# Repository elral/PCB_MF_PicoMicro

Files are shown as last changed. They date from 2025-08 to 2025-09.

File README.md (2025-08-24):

# ✈️ PicoMicro - ProMicro-Compatible Board from Mobiflight

This board is designed as a **drop-in replacement** for the classic Arduino Pro Micro (ATmega32U4), but powered by the **modern Raspberry Pi RP2350A microcontroller**.  
It keeps the same **form factor and pinout** while offering massive improvements in performance, memory, and connectivity — making it the **ideal choice for Mobiflight cockpits**.

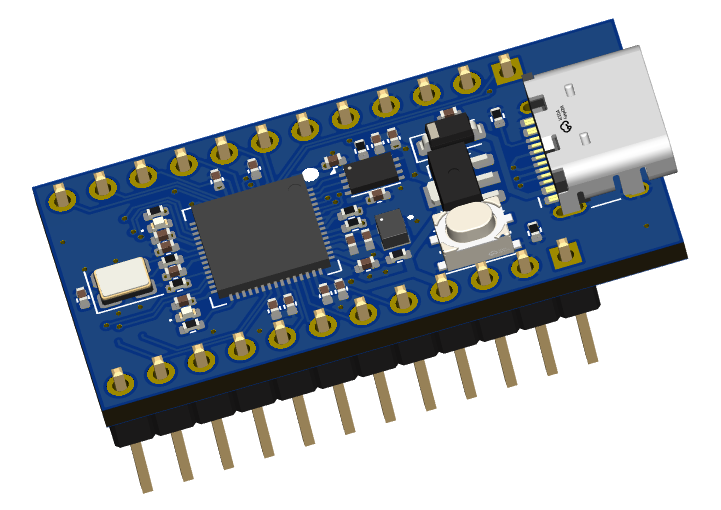
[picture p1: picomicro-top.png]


---

## 🚀 Why PicoMicro for Mobiflight?

### ⚡ Drop-In Upgrade
- Identical footprint & pinout to the Arduino Pro Micro  
- Works with existing wiring and PCB layouts → **no hardware redesign required**  

### 📈 Higher Performance for Complex Cockpits
- **Dual-core ARM Cortex-M33 @ up to 150 MHz** (with FPU & DSP)  
- Handles many encoders, switches, LEDs, and displays simultaneously  
- **512 KB SRAM + up to 16 MB Flash** → no memory limits for complex setups  

### 🔌 Richer Connectivity
- **Native USB 2.0 FS/HS**  

### ⚡ True 5V Compatibility
- **5V-tolerant I/O pins** → safe with legacy 5V sensors, LEDs, and modules  
- Fully compatible with most cockpit electronics  

### 🔋 Efficiency & Reliability
- ARM-based low-power modes for large setups  
- Stable & future-proof, backed by Raspberry Pi Foundation support

---

## ⚠️ Known Limitations vs. Arduino Pro Micro

While this board is highly compatible, there are a few important differences:

1. **Analog Inputs**  
   - Only **A0 to A3** are available (4 total)  
   - Other analog pins present on the Pro Micro are not supported  

2. **5V Output (Pin 21)**  
   - On the Arduino Pro Micro, Pin 21 outputs **5V**  
   - On this board, Pin 21 outputs **3.3V**  

3. **MAX7219 & 5V Requirement**  
   - The MAX7219 driver must still be powered with **5V**  
   - Therefore, an **external 5V source** is required, or you can use **Pin 24 (Vin)**, which provides 5V directly from the USB connector  

4. **Level Shifting for MAX7219**  
   - The MAX7219 requires **5V logic levels**  
   - Use a **level shifter** between the PicoMicro board (3.3V signals) and the MAX7219 inputs  

5. **Bootloader Button**  
   - The board includes a **dedicated BOOT button** to enter USB mass storage boot mode (for firmware flashing).  

---

## 📊 PicoMicro vs. Arduino Pro Micro (ATmega32U4)

| Feature  | PicoMicro ProMicro | Arduino Pro Micro (ATmega32U4) |
|---|---|---|
| MCU | Dual-core ARM Cortex-M33 @ up to 150 MHz, FPU, DSP | 8-bit AVR @ 16 MHz |
| Flash | Up to 16 MB QSPI (typ. 2–8 MB onboard) | 32 KB |
| RAM | 512 KB | 2.5 KB |
| USB | Native USB 2.0 FS/HS, multiple device classes | Native USB 2.0 FS (limited) |
| I/O | **3.3 V logic, 5 V-tolerant pins** | 5 V I/O (native) |
| Analog | 4 (A0–A3 only) | 12 (depending on variant) |
| Extra HW | 2× PIO, Crypto engine, more UART/SPI/I²C | – |
| Power | Low-power modes, efficient ARM design | Limited power saving |

---

## 🔧 Example Wiring (MAX7219 with External 5V)

When using a MAX7219 with this PicoMicro board, note the following:

- The MAX7219 **requires 5V power** for reliable operation.
- The PicoMicro board only provides **3.3V logic**, so a **level shifter** is required on the SPI signals.
- Use the `Vin` pin (Pin 24, USB 5V) as the 5V source if no external supply is available.
- Do **not** use Pin 21 (`5V`), as it only provides 3.3V on this board.

#### Wiring Notes

- **Vin (5V USB)** → **VCC (5V MAX7219)**
- **GND** → **GND**
- **MOSI (3.3V)** → (via level shifter) → **DIN (5V)**
- **SCK (3.3V)** → (via level shifter) → **CLK (5V)**
- **CS (3.3V)** → (via level shifter) → **LOAD/CS (5V)**

Make sure to add a **3.3V → 5V level shifter** on the SPI signals to the MAX7219.

#### Block Diagram

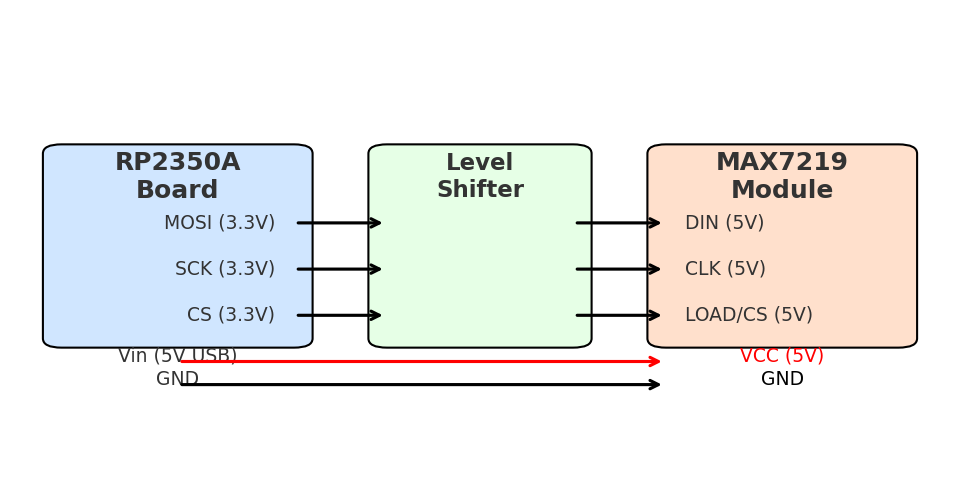
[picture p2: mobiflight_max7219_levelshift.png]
MAX7219 wiring


---

## 🖥 Advantages for Mobiflight Community Devices

Many Mobiflight **Custom Devices** (Community Devices) are more complex and require more memory and processing power than the classic Arduino Pro Micro can provide.  
This board with the **RP2350A** offers clear advantages:

- **More Flash** → room for larger device code and libraries.  
- **More RAM** → essential for OLED displays and complex buffers.  
- **Higher performance** → smoother updates and faster response.  
- **Dual-Core CPU** → allows splitting tasks (e.g., handling displays and inputs in parallel).  
- **PIO offload** → precise timing for LEDs, drivers, or custom protocols  

This makes the PicoMicro board especially well-suited for **community-driven Mobiflight devices**, including setups with **OLED displays** and other resource-demanding modules.

---

## ✈️ Why It Matters for Mobiflight
- **Supports more devices per board** → fewer boards, fewer USB connections
- **Fast response times** → smoother input/output handling with no lag
- **Drop-in compatibility** → works in place of the Pro Micro in your cockpit modules  
- **Future-ready** → while the ATmega32U4 reaches its limits, the PicoMicro provides plenty of headroom for upcoming Mobiflight features  

---

## 📌 Summary
The **PicoMicro** is a **next-generation upgrade** built for Mobiflight cockpit builders:  
✅ More performance & memory  
✅ 5V-tolerant IO  
✅ 100% ProMicro form factor  
✅ Ideal for complex community devices, including OLEDs

> **Upgrade your cockpit today — with transparent compatibility notes for a smooth migration.**

## Additional information

### Bottom View
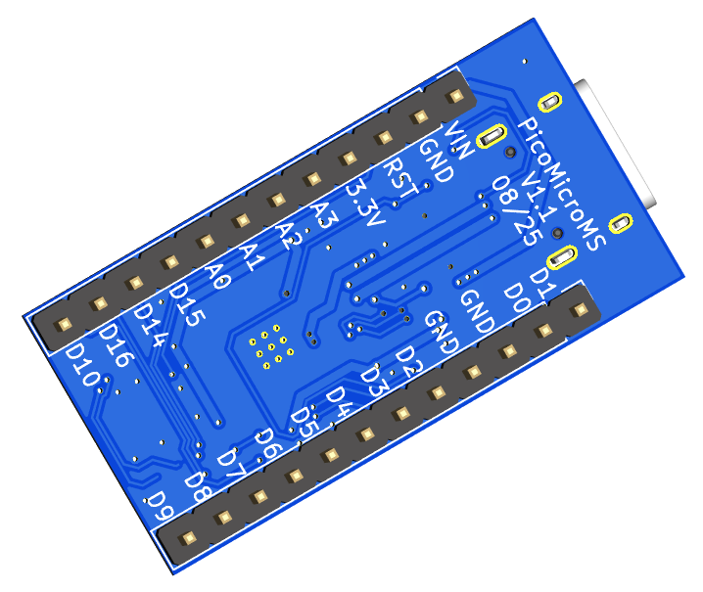
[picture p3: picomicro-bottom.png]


### Schematic
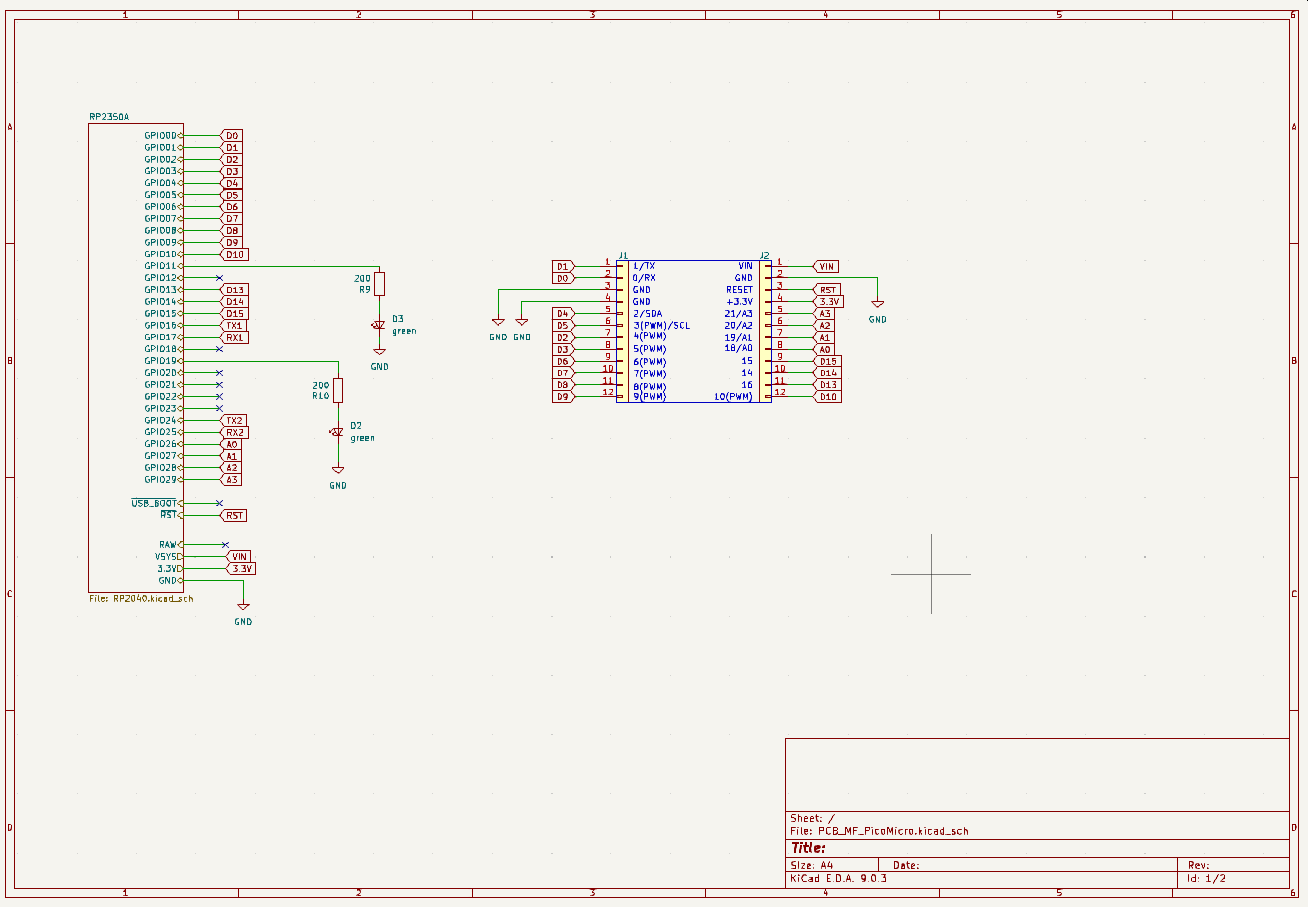
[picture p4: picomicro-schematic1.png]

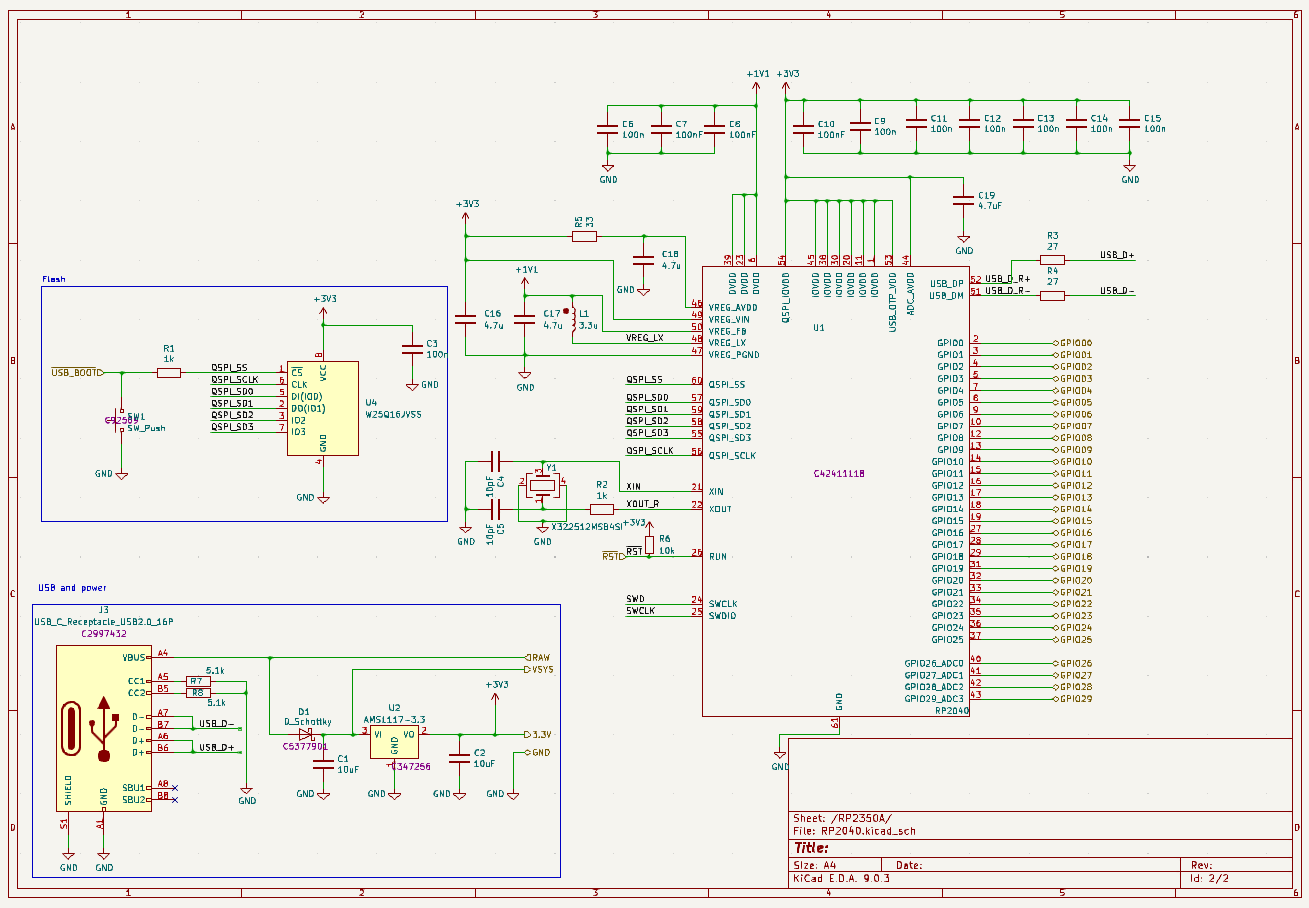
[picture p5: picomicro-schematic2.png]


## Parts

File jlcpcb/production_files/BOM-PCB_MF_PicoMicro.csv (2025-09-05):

Comment | Designator | Footprint | LCSC | Quantity
1k | R1,R2 | R_0402_1005Metric | C11702 | 2
100nF | C10,C11,C12,C13,C14,C15,C3,C6,C7,C8,C9 | C_0402_1005Metric | C1525 | 11
10uF | C1,C2 | C_0402_1005Metric | C15525 | 2
4.7u | C16,C17,C18,C19 | C_0402_1005Metric_small_pads | C23733 | 4
200 | R10,R9 | R_0402_1005Metric | C25087 | 2
27 | R3,R4 | R_0402_1005Metric | C25100 | 2
33 | R5 | R_0402_1005Metric | C25105 | 1
50 | R11,R12 | R_0402_1005Metric | C25120 | 2
10k | R6 | R_0402_1005Metric | C25744 | 1
5.1k | R7,R8 | R_0402_1005Metric | C25905 | 2
W25Q16JVSS | U4 | Winbond_USON-8-1EP_3x2mm_P0.5mm_EP0.2x1.6mm | C2843335 | 1
Conn_01x02_Pin | J7,J8 | JST_ZH_B2B-ZR_1x02_P1.50mm_Vertical | C2845550 | 2
USB_C_Receptacle_USB2.0_16P | J3 | USB_C_Receptacle_HCTL_HC-TYPE-C-16P-01A | C2997432 | 1
10pF | C4,C5 | C_0402_1005Metric | C32949 | 2
AMS1117-3.3 | U2 | SOT-89-3 | C347256 | 1
green | D2,D3 | LED_0402_1005Metric | C401111 | 2
RP2350A | U1 | RP2350A_QFN-60_EP_7.75x7.75_Pitch0.4mm | C42411118 | 1
3.3u | L1 | L_pol_2016 | C42411119 | 1
D_Schottky | D1 | D_SOD-123 | C5377901 | 1
X322512MSB4SI | Y1 | Crystal_SMD_3225-4Pin_3.2x2.5mm | C9002 | 1
SW_Push | SW1 | SW_Push_1P1T_NO_Vertical_Wuerth_434133025816 | C92589 | 1
Conn_01x12 | J2 | PinHeader_1x12_P2.54mm_Vertical |  | 1
Conn_01x12 | J1 | PinHeader_1x12_P2.54mm_Vertical |  | 1

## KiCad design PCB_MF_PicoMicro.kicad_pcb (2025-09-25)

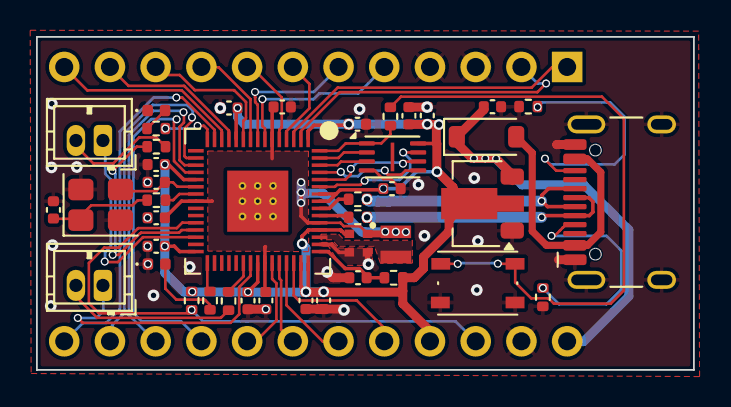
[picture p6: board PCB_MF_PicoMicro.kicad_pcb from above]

Board: 2 copper layers, 36.5 x 18.5 mm, 44 parts (0 on the bottom side), 52 nets.

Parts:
C1, C2: 10uF; C_0402_1005Metric
C3: 100n; C_0402_1005Metric
C4, C5: 10pF; C_0402_1005Metric
C6, C7, C8, C9, C10, C11, C12, C13, C14, C15: 100nF; C_0402_1005Metric
C16, C17: 4.7u; C_0402_1005Metric_small_pads
C18: 4.7u; C_0402_1005Metric
C19: 4.7uF; C_0402_1005Metric
D1: D_Schottky; D_SOD-123
D2, D3: green; LED_0402_1005Metric
J1: PicoMicro
J3: USB_C_Receptacle_USB2.0_16P; USB_C_Receptacle_HCTL_HC-TYPE-C-16P-01A
J7, J8: Conn_01x02_Pin; JST_ZH_B2B-ZR_1x02_P1.50mm_Vertical
L1: 3.3u; L_pol_2016
R1, R2: 1k; R_0402_1005Metric
R3, R4: 27; R_0402_1005Metric
R5: 33; R_0402_1005Metric
R6: 10k; R_0402_1005Metric
R7, R8: 5.1k; R_0402_1005Metric
R9, R10: 200; R_0402_1005Metric
R11, R12: 50; R_0402_1005Metric
SW1: SW_Push; SW_Push_1P1T_NO_Vertical_Wuerth_434133025816
U1: RP2350A; RP2350A_QFN-60_EP_7.75x7.75_Pitch0.4mm
U2: AMS1117-3.3; SOT-89-3
U4: W25Q16JVSS; Winbond_USON-8-1EP_3x2mm_P0.5mm_EP0.2x1.6mm
Y1: X322512MSB4SI; Crystal_SMD_3225-4Pin_3.2x2.5mm

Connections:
3.3V: C2.1, C3.1, C9.1, C10.1, C11.1, C12.1, C13.1, C14.1, C15.1, C16.1, C19.1, J1.21 (+3.3V), R5.1, R6.1, U1.1 (IOVDD), U1.11 (IOVDD), U1.20 (IOVDD), U1.30 (IOVDD), U1.38 (IOVDD), U1.44 (ADC_AVDD), U1.45 (IOVDD), U1.49 (VREG_VIN), U1.53 (USB_OTP_VDD), U1.54 (QSPI_IOVDD), U2.2 (VO), U4.8 (VCC)
+1V1: C6.1, C7.1, C8.1, C17.1, L1.1, U1.6 (DVDD), U1.23 (DVDD), U1.39 (DVDD), U1.50 (VREG_FB)
/RP2350A/GPIO11: R9.2, U1.15 (GPIO11)
/RP2350A/GPIO19: R10.2, U1.31 (GPIO19)
/RP2350A/QSPI_SCLK: U1.56 (QSPI_SCLK), U4.6 (CLK)
/RP2350A/QSPI_SD0: U1.57 (QSPI_SD0), U4.5 (DI(IO0))
/RP2350A/QSPI_SD1: U1.59 (QSPI_SD1), U4.2 (DO(IO1))
/RP2350A/QSPI_SD2: U1.58 (QSPI_SD2), U4.3 (IO2)
/RP2350A/QSPI_SD3: U1.55 (QSPI_SD3), U4.7 (IO3)
/RP2350A/QSPI_SS: R1.1, U1.60 (QSPI_SS), U4.1 (~CS)
/RP2350A/RAW: D1.2 (A), J3.A4 (VBUS), J3.A9 (VBUS), J3.B4 (VBUS), J3.B9 (VBUS)
/RP2350A/USB_D+: J3.A6 (D+), J3.B6 (D+), R3.1
/RP2350A/USB_D-: J3.A7 (D-), J3.B7 (D-), R4.1
/RP2350A/USB_D_R+: R3.2, U1.52 (USB_DP)
/RP2350A/USB_D_R-: R4.2, U1.51 (USB_DM)
/RP2350A/VREG_LX: L1.2, U1.48 (VREG_LX)
/RP2350A/XIN: C4.1, U1.21 (XIN), Y1.3
/RP2350A/XOUT_R: R2.1, U1.22 (XOUT)
/RP2350A/~USB_BOOT: R1.2, SW1.2
A0: J1.17 (18(A0)), U1.40 (GPIO26_ADC0)
A1: J1.18 (19(A1)), U1.41 (GPIO27_ADC1)
A2: J1.19 (20(A2)), U1.42 (GPIO28_ADC2)
A3: J1.20 (21(A3)), U1.43 (GPIO29_ADC3)
D0: J1.2 (0(PWM)/RX), U1.2 (GPIO0)
D1: J1.1 (1(PWM)/TX), U1.3 (GPIO1)
D2: J1.7 (4(PWM)), U1.4 (GPIO2)
D3: J1.8 (5(PWM)), U1.5 (GPIO3)
D4: J1.5 (2(PWM)/SDA), U1.7 (GPIO4)
D5: J1.6 (3(PWM)/SCL), U1.8 (GPIO5)
D6: J1.9 (6(PWM)), U1.9 (GPIO6)
D7: J1.10 (7(PWM)), U1.10 (GPIO7)
D8: J1.11 (8(PWM)), U1.12 (GPIO8)
D9: J1.12 (9(PWM)), U1.13 (GPIO9)
D10: J1.13 (10(PWM)), U1.14 (GPIO10)
D13: J1.14 (16), U1.17 (GPIO13)
D14: J1.15 (14), U1.18 (GPIO14)
D15: J1.16 (15), U1.19 (GPIO15)
GND: C1.2, C2.2, C3.2, C4.2, C5.2, C6.2, C7.2, C8.2, C9.2, C10.2, C11.2, C12.2, C13.2, C14.2, C15.2, C16.2, C17.2, C18.2, C19.2, D2.1 (K), D3.1 (K), J1.3 (GND), J1.4 (GND), J1.23 (GND), J3.A1 (GND), J3.A12 (GND), J3.B1 (GND), J3.B12 (GND), J3.S1 (SHIELD), R7.1, R8.1, SW1.1, U1.47 (VREG_PGND), U1.61 (GND), U2.1 (GND), U4.4 (GND), Y1.2, Y1.4
unnamed: C5.1, R2.2, Y1.1
unnamed: D2.2 (A), R10.1
unnamed: D3.2 (A), R9.1
unnamed: J3.A5 (CC1), R7.2
unnamed: J3.B5 (CC2), R8.2
unnamed: J7.2, R11.1
unnamed: J8.2, R12.1
unnamed: C18.1, R5.2, U1.46 (VREG_AVDD)
RST: J1.22 (RESET), R6.2, U1.26 (RUN)
RX1: J7.1, U1.28 (GPIO17)
RX2: J8.1, U1.37 (GPIO25)
TX1: R11.2, U1.27 (GPIO16)
TX2: R12.2, U1.36 (GPIO24)
VIN: C1.1, D1.1 (K), J1.24 (VIN), U2.3 (VI)

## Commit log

2025-08-09 first upload
    [PCB_MF_PicoMicro.kicad_pcb, PCB_MF_PicoMicro.kicad_sch, RP2040.kicad_sch]
2025-08-09 first changes for RP2350A
    [PCB_MF_PicoMicro.kicad_pcb, PCB_MF_PicoMicro.kicad_sch, RP2040.kicad_sch]
2025-08-10 power supply lines routed
    [PCB_MF_PicoMicro.kicad_pcb, RP2040.kicad_sch]
2025-08-11 fixed all warnings/errors
    [PCB_MF_PicoMicro.kicad_pcb, RP2040.kicad_sch]
2025-08-11 add parts for 1.1V regulator
    [PCB_MF_PicoMicro.kicad_pcb, RP2040.kicad_sch]
2025-08-12 add LED, make board smaller
    [PCB_MF_PicoMicro.kicad_pcb, PCB_MF_PicoMicro.kicad_sch, RP2040.kicad_sch]
2025-08-14 add 2nd LED
    [PCB_MF_PicoMicro.kicad_pcb, PCB_MF_PicoMicro.kicad_sch]
2025-08-14 add missing R for LEDs, add production files for JLCPCB
    [BOM-PCB_MF_PicoMicro.csv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]
2025-08-14 minor layout optimazations, update production files
    [CPL-PCB_MF_PicoMicro.csv, PCB_MF_PicoMicro-CuBottom.gbr, PCB_MF_PicoMicro-CuTop.gbr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]
2025-08-14 update production files acc. order
    [BOM-PCB_MF_PicoMicro.csv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]
2025-08-22 change ProMicro footprint to standard connector
    commit eacd6e6b7c88736312cbb7fe5e411177d7c22398
    Author: elral <3263285+elral@users.noreply.github.com>
    Date: Thu Aug 21 06:40:23 2025 +0200
    replace ProMicro against pin header connectors
    [PCB_MF_PicoMicro.kicad_pcb, PCB_MF_PicoMicro.kicad_sch]
2025-08-22 add cap for AVDD, fix wrong cap value 1V1
    [BOM-PCB_MF_PicoMicro.csv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]
2025-08-23 add schematic, new chapter for additional informatio
2025-08-27 better routing of USB_BOOT track
    [PCB_MF_PicoMicro.kicad_pcb]
2025-09-01 serial resistor for TX line
    [PCB_MF_PicoMicro.kicad_pcb, PCB_MF_PicoMicro.kicad_sch]
2025-09-01 route both additional resistors
    [PCB_MF_PicoMicro.kicad_pcb, PCB_MF_PicoMicro.kicad_sch, RP2040.kicad_sch]
2025-09-01 update production files
    [BOM-PCB_MF_PicoMicro.csv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]
2025-09-04 Swap TX/RX line from connection to slave
    * swap tx line to slave, better arrangement of parts
    * better positioning of parts
    [PCB_MF_PicoMicro.kicad_pcb, PCB_MF_PicoMicro.kicad_sch]
2025-09-10 add SDA and SCL markings
    [PCB_MF_PicoMicro.kicad_pcb]
2025-09-21 use new PicoMicro Symbol and footprint
    [PCB_MF_PicoMicro.kicad_pcb, PCB_MF_PicoMicro.kicad_sch]
2025-09-25 PicoMicro footprint updated
    [PCB_MF_PicoMicro.kicad_pcb]
